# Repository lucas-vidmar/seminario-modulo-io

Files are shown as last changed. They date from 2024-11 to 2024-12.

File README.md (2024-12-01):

# Módulo Input / Output (I/O) para entornos educativos

> **Autores:**
> - [Lucas Vidmar](https://github.com/lucas-vidmar)
> - [Joaquín Bergmann](https://github.com/JoacoBerg)
> - [Lucas Boiero](https://github.com/boierito)
>
> **Institución:**
> - [Universidad Argentina de la Empresa (UADE)](https://www.uade.edu.ar/)

## Descripción

Este proyecto consiste en un módulo de entrada/salida (I/O) para entornos educativos, que permite a los estudiantes interactuar con sensores y actuadores a través de una interfaz gráfica de usuario (GUI) en un navegador web. El módulo I/O se comunica con el microcontrolador a través de una interfaz I2C, y proporciona una API RESTful para controlar los pines GPIO, los convertidores analógico-digital (ADC) y digital-analógico (DAC), y los codificadores rotatorios.

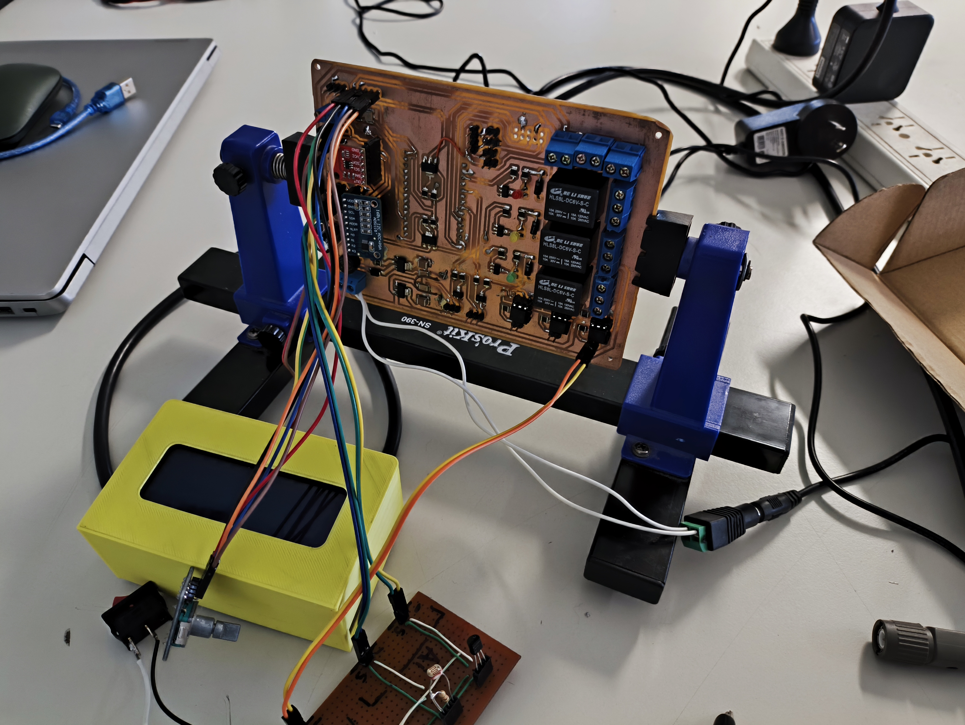
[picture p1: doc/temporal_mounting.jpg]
Montaje

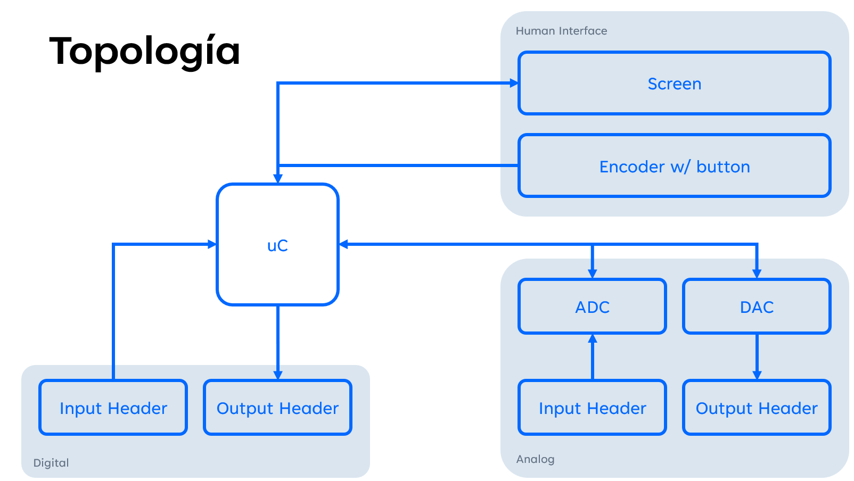
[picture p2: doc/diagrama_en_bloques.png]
Diagrama en bloques

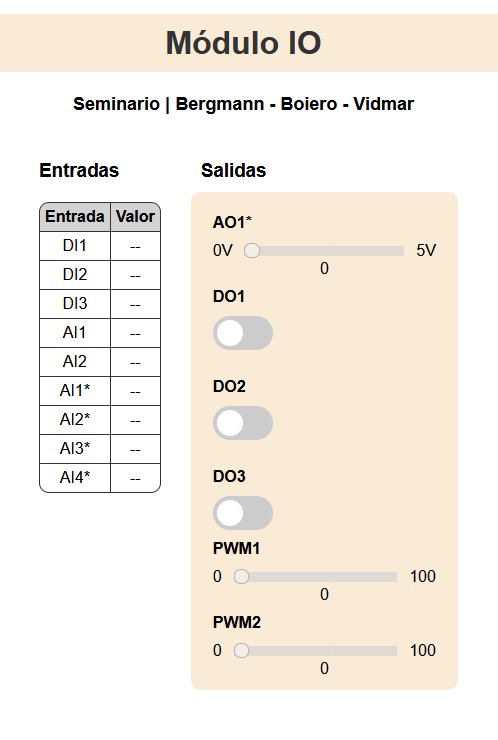
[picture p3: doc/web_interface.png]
Interfaz web


## Diseño de hardware

### Pinout

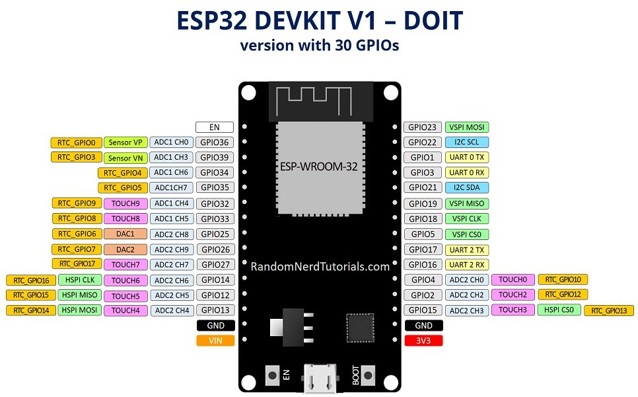
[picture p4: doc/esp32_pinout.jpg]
ESP32 Pinout

| Label | GPIO | Input/Output | Pines utilizados | Modo  |
|---|---|---|---|---|
| D2 | 2 | I/O | Pantalla | CS |
| D4 | 4 | I/O | PWM | PWM |
| D5 | 5 | I/O | PWM | PWM |
| D12 | 12 | I/O | Encoder | CLK |
| D13 | 13 | I/O | Encoder | DT |
| D14 | 14 | I/O | Encoder | SW |
| D15 | 15 | I/O | DO | DO |
| RX2 | 16 | I/O | U2_RXD | U2_RXD|
| TX2 | 17 | I/O | U2_TXD | U2_TXD|
| D18 | 18 | I/O | Pantalla | SCK |
| D19 | 19 | I/O | Pantalla | MISO  |
| D21 | 21 | I/O | I2C | SDA |
| D22 | 22 | I/O | I2C | SLC |
| D23 | 23 | I/O | Pantalla | MOSI  |
| D26 | 26 | I/O | DI | DI |
| D27 | 27 | I/O | DI | DI |
| D32 | 32 | I/O | DO | DO |
| D33 | 33 | I/O | DO | DO |
| D34 | 34 | I | ADC interno | ADC |
| D35 | 35 | I | ADC interno | ADC |
| VP | 36 | I | DI | DI |

### [Esquemático](kicad/Modulo%20IO%20Seminario.kicad_sch)

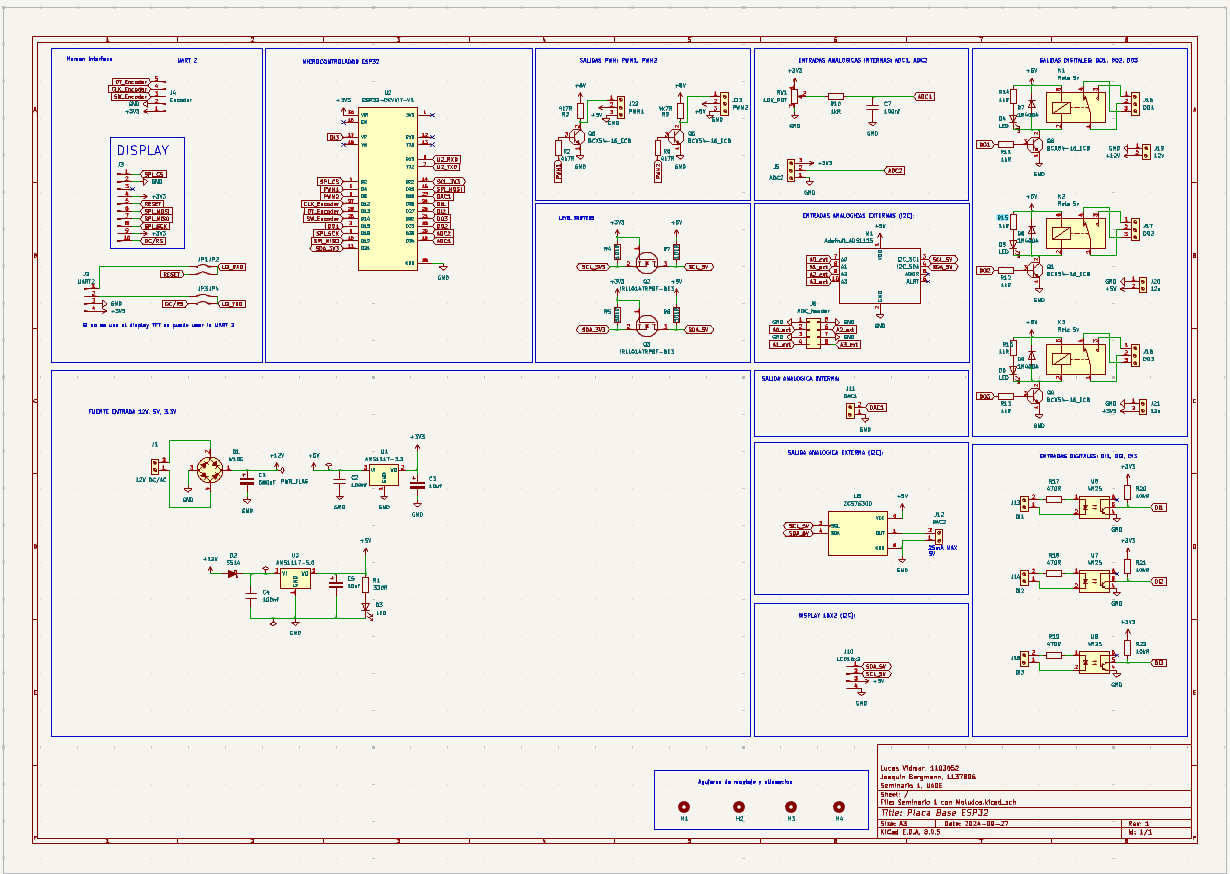
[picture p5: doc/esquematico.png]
Esquemático


### [PCB](kicad/Modulo%20IO%20Seminario.kicad_pcb)

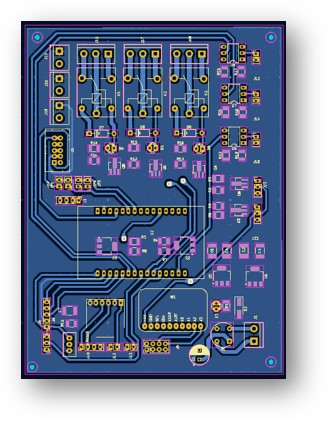
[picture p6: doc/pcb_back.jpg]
PCB Back

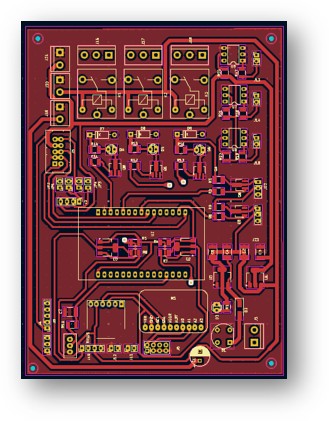
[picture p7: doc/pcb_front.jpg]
PCB Front

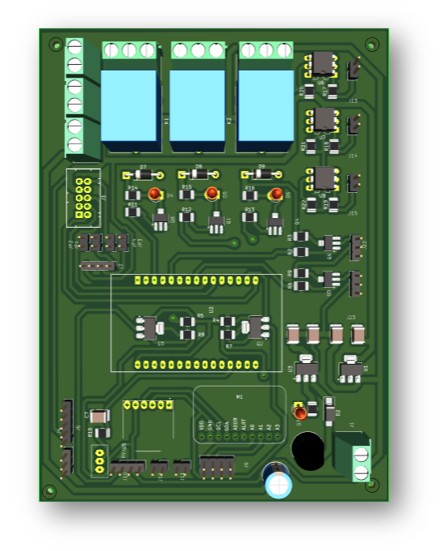
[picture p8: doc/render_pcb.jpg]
Render PCB


## Documentación de código

### [main.h](include/main.h)
Este archivo contiene las declaraciones principales del proyecto, incluidas las declaraciones de funciones para los manejadores de HTML, la impresión de menús, la lógica FSM y el control de GPIO.

### [led.h](include/led.h)
Este archivo contiene la declaración de la clase `BuiltInLed`, que proporciona métodos para controlar el LED incorporado en un microcontrolador.

### [lcdsim.h](include/lcdsim.h)
Este archivo contiene la declaración de la clase `SimulatedLCD`, que simula una pantalla LCD para fines de prueba.

### [i2c.h](include/i2c.h)
Este archivo contiene la declaración de la clase `I2C`, que proporciona métodos para inicializar la interfaz I2C y realizar operaciones de lectura y escritura en el bus I2C.

### [gpio.h](include/gpio.h)
Este archivo contiene la declaración de la clase `GPIO` y sus clases derivadas `DigitalGPIO` y `AnalogGPIO`, que proporcionan métodos para configurar, leer y escribir en los pines GPIO.

### [encodersim.h](include/encodersim.h)
Este archivo contiene la declaración de la clase `SimulatedEncoder`, que simula un codificador para fines de prueba.

### [encoder.h](include/encoder.h)
Este archivo contiene la declaración de la clase `Encoder`, que proporciona métodos para interactuar con un codificador rotatorio.

### [dac.h](include/dac.h)
Este archivo contiene la declaración de la clase `DAC`, que proporciona métodos para inicializar y controlar un Convertidor Digital a Analógico (DAC) a través de I2C.

### [adc.h](include/adc.h)
Este archivo contiene la declaración de la clase `ADC`, que proporciona métodos para interactuar con un Convertidor Analógico a Digital (ADC) a través de I2C.

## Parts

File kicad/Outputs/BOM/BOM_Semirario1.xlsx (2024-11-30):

Reference |  | Value | Footprint | Qty | Mfg Part # | Mouser | Reemplazo
C1 |  | 680uF | Capacitor_THT:CP_Radial_D8.0mm_P3.80mm | 1
C2;C4;C6;C7;C8;C9 | x | 100nf | Capacitor_SMD:C_1812_4532Metric_Pad1.57x3.40mm_HandSolder | 6 | -- valores mixtos -- | 18123C104JAT2A
C3;C5 | x | 10uf | Capacitor_SMD:C_1812_4532Metric_Pad1.57x3.40mm_HandSolder | 2 |  | 1812YC106MAT2A
D1 | x | W10G | Diode_THT:Diode_Bridge_Round_D9.8mm | 1
D2 | x | SS14 | Diode_SMD:D_SMA_Handsoldering | 1 |  | SS14 | 1N5819
D3;D4;D5;D6 | x | LED | LED_THT:LED_D3.0mm | 4
D7;D8;D9 | x | 1N4004 | Diode_THT:D_DO-41_SOD81_P10.16mm_Horizontal | 3
J1 |  | 12V DC/AC | TerminalBlock:TerminalBlock_bornier-2_P5.08mm | 1
J2 |  | UART2 | Connector_PinHeader_2.54mm:PinHeader_1x04_P2.54mm_Vertical | 1
J3 |  | Conn_01x10_Pin | easyeda:CONN-TH_10P-P2.54_B10B-XADSS-N-LF-SN | 1 | B10B-XADSS-N(LF)(SN)
J4 |  | Encoder | Connector_PinHeader_2.54mm:PinHeader_1x05_P2.54mm_Vertical | 1
J5 |  | PWM1 | Connector_PinHeader_2.54mm:PinHeader_1x02_P2.54mm_Vertical | 1
J6 |  | PWM2 | Connector_PinHeader_2.54mm:PinHeader_1x02_P2.54mm_Vertical | 1
J7 |  | ADC3 | Connector_PinHeader_2.54mm:PinHeader_1x02_P2.54mm_Vertical | 1
J8 |  | ADC4 | Connector_PinHeader_2.54mm:PinHeader_1x02_P2.54mm_Vertical | 1
J9 |  | ADC2 | Connector_PinHeader_2.54mm:PinHeader_1x02_P2.54mm_Vertical | 1
J10 |  | LCD16x2 | Connector_PinHeader_2.54mm:PinHeader_1x04_P2.54mm_Vertical | 1
J11 |  | DAC1 | Connector_PinHeader_2.54mm:PinHeader_1x02_P2.54mm_Vertical | 1
J12 |  | DAC2 | Connector_PinHeader_2.54mm:PinHeader_1x02_P2.54mm_Vertical | 1
J13 |  | DI1 | Connector_PinHeader_2.54mm:PinHeader_1x02_P2.54mm_Vertical | 1
J14 |  | DI2 | Connector_PinHeader_2.54mm:PinHeader_1x02_P2.54mm_Vertical | 1
J15 |  | DI3 | Connector_PinHeader_2.54mm:PinHeader_1x02_P2.54mm_Vertical | 1
J16 |  | DO1 | TerminalBlock:TerminalBlock_bornier-3_P5.08mm | 1
J17 |  | DO2 | TerminalBlock:TerminalBlock_bornier-3_P5.08mm | 1
J18 |  | DO3 | TerminalBlock:TerminalBlock_bornier-3_P5.08mm | 1
J19;J20;J21 |  | 12v | TerminalBlock:TerminalBlock_bornier-2_P5.08mm | 3
JP1;JP2;JP3;JP4 |  | Jumper_2_Bridged | Connector_PinHeader_2.54mm:PinHeader_1x02_P2.54mm_Vertical | 4
K1;K2;K3 | x | Rele 5v | Relay_THT:Relay_SPDT_SANYOU_SRD_Series_Form_C | 3
Q1;Q4;Q5;Q6;Q8 | x | BCX54-16_ECB | easyeda:SOT-89_Custom | 5 |  | BCX54-16,115
Q2;Q3 | x | IRLL014TRPBF-BE3 | easyeda:SOT-223_Custom | 2 |  | IRLL014TRPBF-BE3
R1 | x | 330R | Resistor_SMD:R_1210_3225Metric_Pad1.30x2.65mm_HandSolder | 1 |  | CRCW1210330RFKEAHP
R2;R3;R6;R9 | x | 4k7R | Resistor_SMD:R_1210_3225Metric_Pad1.30x2.65mm_HandSolder | 4 |  | CRCW12104K70JNEAIF
R4;R5;R7;R8;R20;R21;R22 | x | 10kR | Resistor_SMD:R_1210_3225Metric_Pad1.30x2.65mm_HandSolder | 7 | RT0805BRD0710KL | CRCW121010K0JNEAIF
R10;R11;R12;R13;R14;R15;R16 | x | 1kR | Resistor_SMD:R_1210_3225Metric_Pad1.30x2.65mm_HandSolder | 7 |  | CRCW12101K00JNEAIF
R17;R18;R19 | x | 470R | Resistor_SMD:R_1210_3225Metric_Pad1.30x2.65mm_HandSolder | 3 |  | CRCW1210470RFKEAHP
RV1 | x | 10K_POT | Potentiometer_THT:Potentiometer_Bourns_3296W_Vertical | 1
U1 | x | AMS1117-3.3 | Package_TO_SOT_SMD:SOT-223-3_TabPin2 | 1 |  | LM1117MPX-3.3/NOPB
U2 | x | ESP32-DEVKIT-V1 | esp32:ESP_Test | 1
U3 | x | AMS1117-5.0 | Package_TO_SOT_SMD:SOT-223-3_TabPin2 | 1 |  | LM1117MPX-5.0/NOPB
U4 | x | MCP4725A0T | easyeda:SOT-23-6_L2.9-W1.6-P0.95-LS2.8-BR | 1 | MCP4725A0T-E/CH | MCP4725A0T-E/CH
U5 | x | ADS1115IDGS | Package_SO:TSSOP-10_3x3mm_P0.5mm | 1 |  | ADS1115IDGST
U6;U7;U8 | x | 4N25 | Package_DIP:DIP-6_W7.62mm | 3 |  | 4N25

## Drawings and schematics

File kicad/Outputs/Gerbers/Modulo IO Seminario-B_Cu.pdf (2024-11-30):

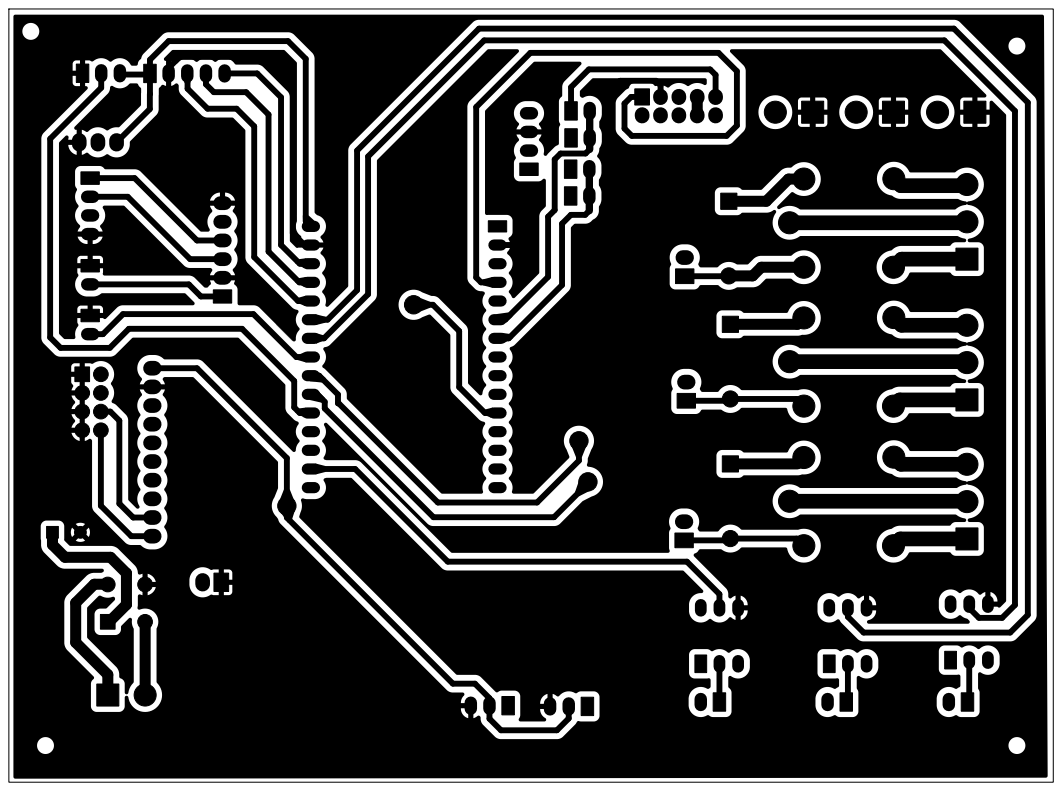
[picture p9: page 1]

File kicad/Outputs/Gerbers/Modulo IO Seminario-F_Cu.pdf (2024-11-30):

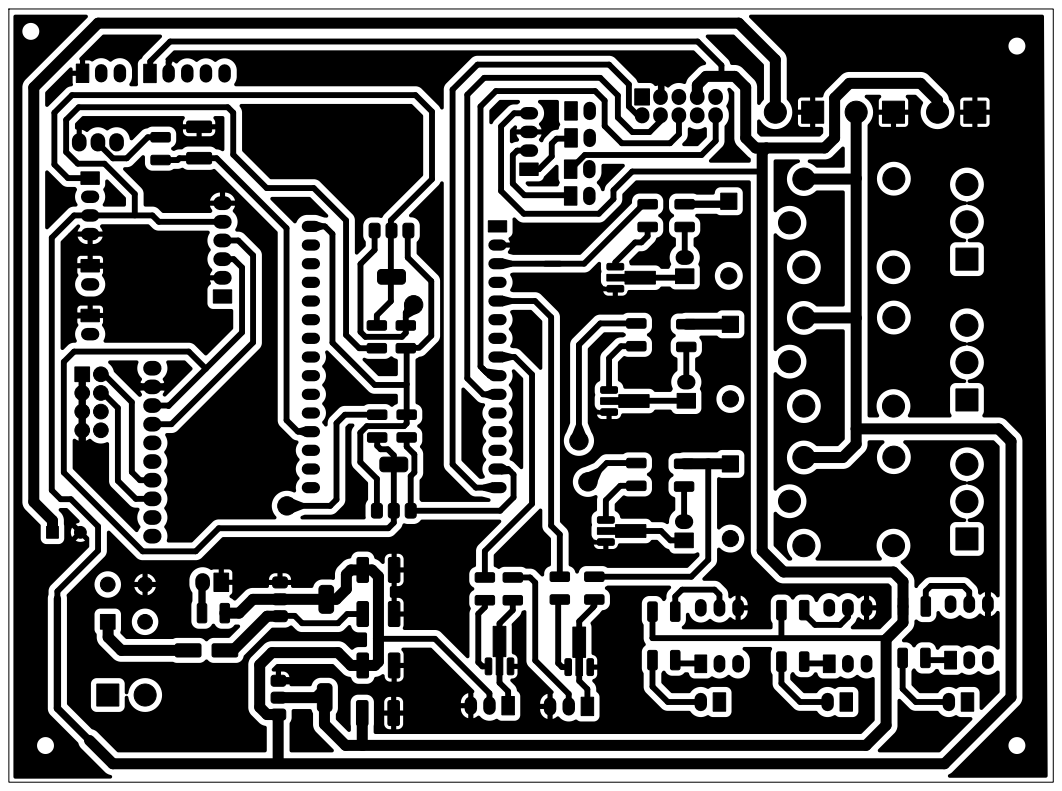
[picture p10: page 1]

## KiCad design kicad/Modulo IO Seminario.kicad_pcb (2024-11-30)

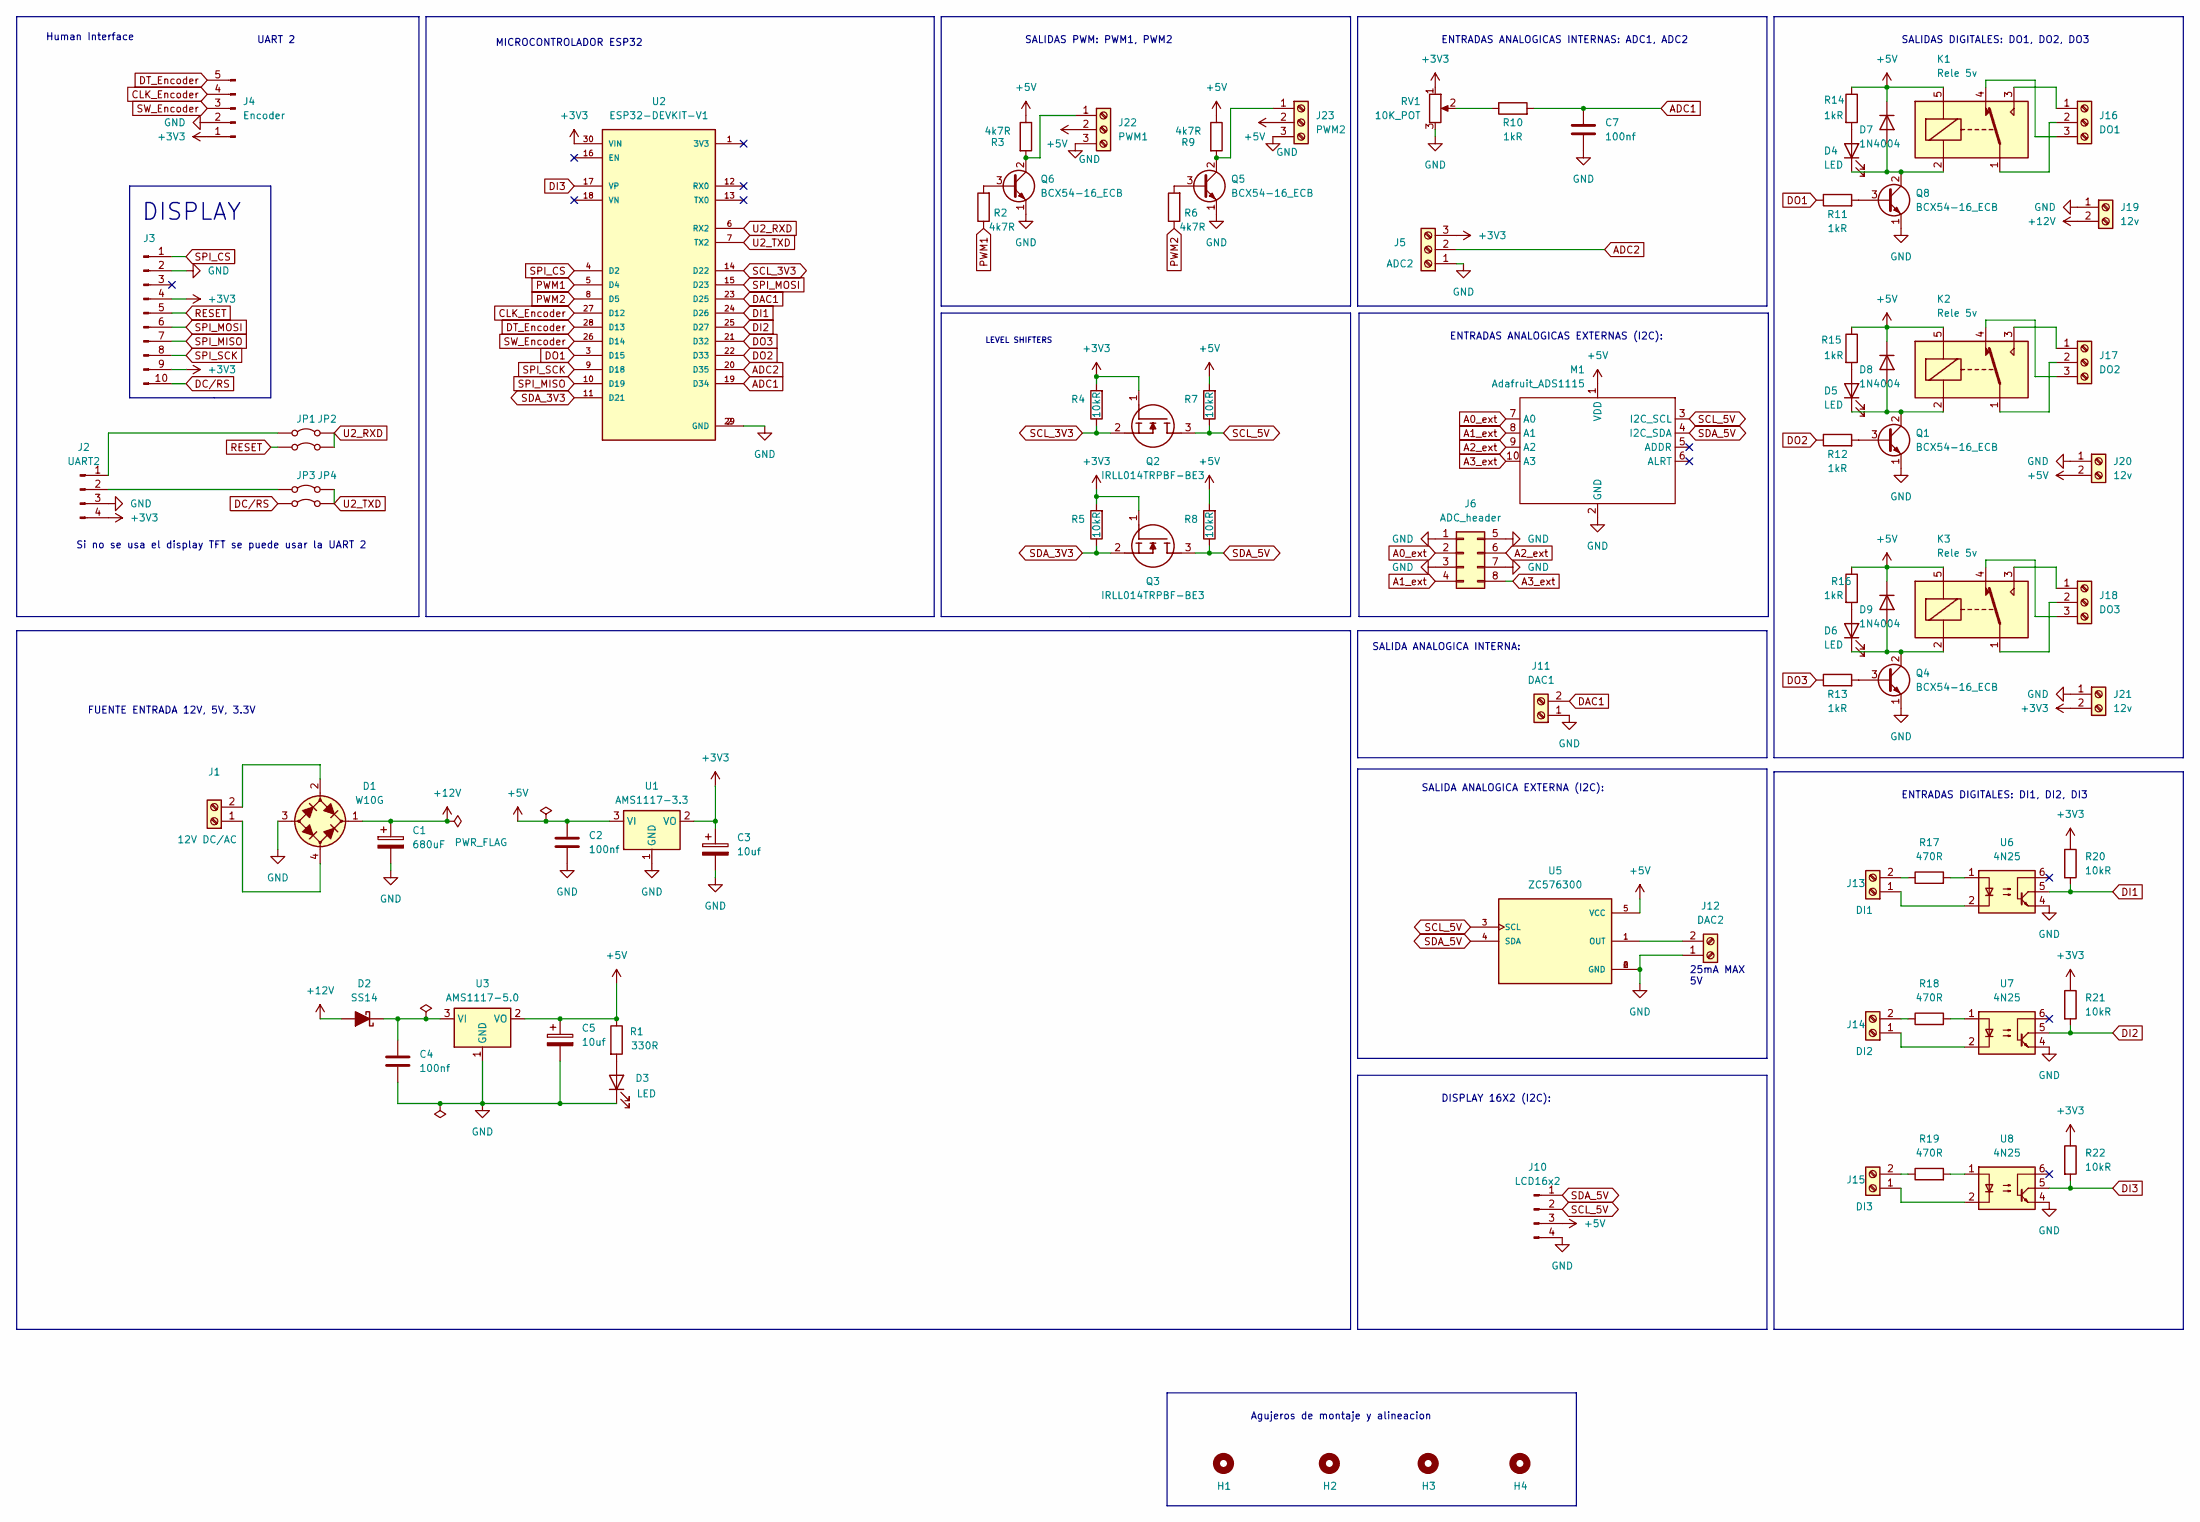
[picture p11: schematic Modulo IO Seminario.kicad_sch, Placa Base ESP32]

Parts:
C1: 680uF; CP_Radial_D8.0mm_P3.80mm
C2, C4, C7: 100nf; C_1812_4532Metric_Pad1.57x3.40mm_HandSolder; Mouser 18123C104JAT2A
C3, C5: 10uf; C_1812_4532Metric_Pad1.57x3.40mm_HandSolder; Mouser 1812YC106MAT2A
D1: W10G; Diode_Bridge_Round_D9.8mm
D2: SS14; D_SMA_Handsoldering; Mouser SS14
D3, D4, D5, D6: LED; led3mm
D7, D8, D9: 1N4004; D_DO-41_SOD81_P10.16mm_Horizontal
H1, H2, H3, H4: MountingHole_2.1mm
J1: 12V DC/AC; TerminalBlock_bornier-2_P5.08mm
J2: UART2; PinHeader_1.4_large
J3: Conn_01x10_Pin; CONN-TH_10P-P2.54_B10B-XADSS-N-LF-SN; Mfg Part # B10B-XADSS-N(LF)(SN); LCSC Part # C160278
J4: Encoder; PinHeader_1.5large
J5: ADC2; PinHeader_1.3_large
J6: ADC_header; PinHeader_2x04_custom
J10: LCD16x2; PinHeader_1.4_large
J11: DAC1; PinHeader_1.2_large
J12: DAC2; PinHeader_1.2_large
J13: DI1; PinHeader_1.2_large
J14: DI2; PinHeader_1.2_large
J15: DI3; PinHeader_1.2_large
J16: DO1; TerminalBlock_bornier-3_P5.08mm
J17: DO2; TerminalBlock_bornier-3_P5.08mm
J18: DO3; TerminalBlock_bornier-3_P5.08mm
J19, J20, J21: 12v; TerminalBlock_bornier-2_P5.08mm
J22: PWM1; PinHeader_1.3_large
J23: PWM2; PinHeader_1.3_large
JP1, JP2, JP3, JP4: Jumper_2_Bridged; PinHeader_1.2_large
K1, K2, K3: Rele 5v; Relay_SPDT_SANYOU_SRD_Series_Form_C
M1: Adafruit_ADS1115
Q1, Q4, Q5, Q6, Q8: BCX54-16_ECB; SOT-89_Custom; Mouser BCX54-16,115
Q2, Q3: IRLL014TRPBF-BE3; SOT-223_Custom; LCSC Part # C82045
R1: 330R; R_1210_3225Metric_Pad1.30x2.65mm_HandSolder; Mouser CRCW1210330RFKEAHP
R2, R3, R6, R9: 4k7R; R_1210_3225Metric_Pad1.30x2.65mm_HandSolder; Mouser CRCW12104K70JNEAIF
R4, R5, R7, R8: 10kR; R_1210_3225Metric_Pad1.30x2.65mm_HandSolder; Tolerancia 5%; Mfg Part # RT0805BRD0710KL; LCSC Part # C110775
R10, R11, R12, R13, R14, R15, R16: 1kR; R_1210_3225Metric_Pad1.30x2.65mm_HandSolder; Mouser CRCW12101K00JNEAIF
R17, R18, R19: 470R; R_1210_3225Metric_Pad1.30x2.65mm_HandSolder; Mouser CRCW1210470RFKEAHP
R20, R21, R22: 10kR; R_1210_3225Metric_Pad1.30x2.65mm_HandSolder; Mfg Part # RT0805BRD0710KL; Mouser CRCW121010K0JNEAIF
RV1: 10K_POT; PoteBourns
U1: AMS1117-3.3; SOT-223-3_TabPin2; Mouser LM1117MPX-3.3/NOPB
U2: ESP32-DEVKIT-V1; ESP_Test; PARTREV N/A
U3: AMS1117-5.0; SOT-223-3_TabPin2; Mouser LM1117MPX-5.0/NOPB
U5: ZC576300; MODULE_ZC576300; PARTREV v14
U6, U7, U8: 4N25; DIP-6_W7.62mm_LongPads; Mouser 4N25

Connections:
+3V3: C3.1, J2.4, J3.4, J3.9, J4.1, J5.3, J21.2, Q2.1 (G), Q3.1 (G), R4.2, R5.2, R20.1, R21.1, R22.1, RV1.1, U1.2 (VO), U2.30 (VIN)
+5V: C2.1, C5.1, D7.1 (K), D8.1 (K), D9.1 (K), J10.3, J20.2, J22.2, J23.2, K1.5, K2.5, K3.5, M1.1 (VDD), R1.1, R3.1, R7.2, R8.2, R9.1, R14.1, R15.1, R16.1, U1.3 (VI), U3.2 (VO), U5.5 (VCC)
+12V: C1.1, D1.1 (+), D2.2 (A), J19.2
A0_ext: J6.2, M1.7 (A0)
A1_ext: J6.4, M1.8 (A1)
A2_ext: J6.6, M1.9 (A2)
A3_ext: J6.8, M1.10 (A3)
ADC1: C7.1, R10.2, U2.19 (D34)
ADC2: J5.2, U2.20 (D35)
CLK_Encoder: J4.4, U2.27 (D12)
DAC1: J11.2, U2.23 (D25)
DC/RS: J3.10, JP4.1 (A)
DI1: R20.2, U2.24 (D26), U6.5
DI2: R21.2, U2.25 (D27), U7.5
DI3: R22.2, U2.17 (VP), U8.5
DO1: R11.1, U2.3 (D15)
DO2: R12.1, U2.22 (D33)
DO3: R13.1, U2.21 (D32)
DT_Encoder: J4.5, U2.28 (D13)
GND: C1.2, C2.2, C3.2, C4.2, C5.2, C7.2, D1.3 (-), D3.1 (K), J2.3, J3.2, J4.2, J5.1, J6.1, J6.3, J6.5, J6.7, J10.4, J11.1, J12.1, J19.1, J20.1, J21.1, J22.3, J23.3, M1.2 (GND), Q1.1 (E), Q4.1 (E), Q5.1 (E), Q6.1 (E), Q8.1 (E), RV1.3, U1.1 (GND), U2.2 (GND), U2.29 (GND), U3.1 (GND), U5.2 (GND), U5.6 (GND), U6.4, U7.4, U8.4
unnamed: D1.2 (1), J1.2
unnamed: D1.4 (2), J1.1
unnamed: C4.1, D2.1 (K), U3.3 (VI)
unnamed: D3.2 (A), R1.2
unnamed: D4.2 (A), R14.2
unnamed: D4.1 (K), D7.2 (A), K1.2, Q8.2 (C)
unnamed: D5.2 (A), R15.2
unnamed: D5.1 (K), D8.2 (A), K2.2, Q1.2 (C)
unnamed: D6.2 (A), R16.2
unnamed: D6.1 (K), D9.2 (A), K3.2, Q4.2 (C)
unnamed: J2.1, JP1.1 (A)
unnamed: J2.2, JP3.1 (A)
unnamed: J12.2, U5.1 (OUT)
unnamed: J13.1, U6.2
unnamed: J13.2, R17.1
unnamed: J14.1, U7.2
unnamed: J14.2, R18.1
unnamed: J15.1, U8.2
unnamed: J15.2, R19.1
unnamed: J16.1, K1.3
unnamed: J16.2, K1.1
unnamed: J16.3, K1.4
unnamed: J17.1, K2.3
unnamed: J17.2, K2.1
unnamed: J17.3, K2.4
unnamed: J18.1, K3.3
unnamed: J18.2, K3.1
unnamed: J18.3, K3.4
unnamed: J22.1, Q6.2 (C), R3.2
unnamed: J23.1, Q5.2 (C), R9.2
unnamed: Q1.3 (B), R12.2
unnamed: Q4.3 (B), R13.2
unnamed: Q5.3 (B), R6.2
unnamed: Q6.3 (B), R2.2
unnamed: Q8.3 (B), R11.2
unnamed: R10.1, RV1.2
unnamed: R17.2, U6.1
unnamed: R18.2, U7.1
unnamed: R19.2, U8.1
PWM1: R2.1, U2.5 (D4)
PWM2: R6.1, U2.8 (D5)
RESET: J3.5, JP2.1 (A)
SCL_3V3: Q2.2 (S), R4.1, U2.14 (D22)
SCL_5V: J10.2, M1.3 (I2C_SCL), Q2.3 (D), R7.1, U5.3 (SCL)
SDA_3V3: Q3.2 (S), R5.1, U2.11 (D21)
SDA_5V: J10.1, M1.4 (I2C_SDA), Q3.3 (D), R8.1, U5.4 (SDA)
SPI_CS: J3.1, U2.4 (D2)
SPI_MISO: J3.7, U2.10 (D19)
SPI_MOSI: J3.6, U2.15 (D23)
SPI_SCK: J3.8, U2.9 (D18)
SW_Encoder: J4.3, U2.26 (D14)
U2_RXD: JP1.2 (B), JP2.2 (B), U2.6 (RX2)
U2_TXD: JP3.2 (B), JP4.2 (B), U2.7 (TX2)

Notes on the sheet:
SALIDA ANALOGICA INTERNA:
UART 2
Si no se usa el display TFT se puede usar la UART 2
Agujeros de montaje y alineacion
25mA MAX 5V
MICROCONTROLADOR ESP32
ENTRADAS DIGITALES: DI1, DI2, DI3
DISPLAY 16X2 (I2C):
SALIDA ANALOGICA EXTERNA (I2C):
ENTRADAS ANALOGICAS INTERNAS: ADC1, ADC2
FUENTE ENTRADA 12V, 5V, 3.3V
ENTRADAS ANALOGICAS EXTERNAS (I2C):
Human Interface
SALIDAS DIGITALES: DO1, DO2, DO3
LEVEL SHIFTERS
DISPLAY
SALIDAS PWM: PWM1, PWM2

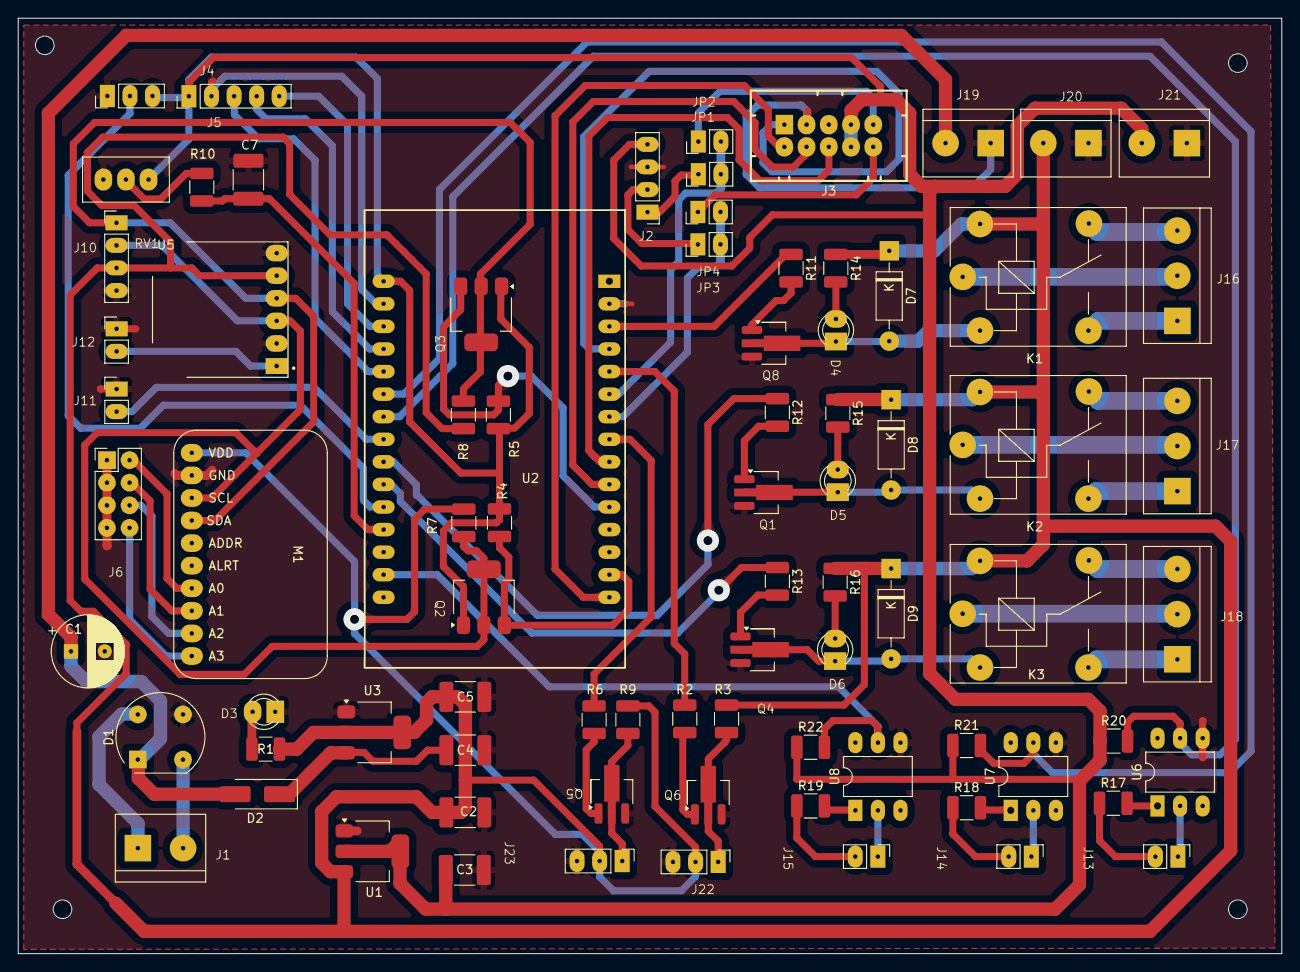
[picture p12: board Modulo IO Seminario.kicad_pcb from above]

Board: 2 copper layers, 142.2 x 105.2 mm, 84 parts (0 on the bottom side), 73 nets.

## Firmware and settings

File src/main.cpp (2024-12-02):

#include "main.h"

bool print = true;
bool wifiConfig = true;

/* ------- Perifericos ------- */
BuiltInLed led = BuiltInLed();
I2C i2c = I2C();
DAC dac = DAC();
ADC adc = ADC();
#ifdef USE_LCD
LiquidCrystal_I2C lcd(0x27, 20, 4);  // Crear el objeto lcd con dirección 0x3F y 20 columnas x 4 filas
#else
SimulatedLCD lcd = SimulatedLCD();
#endif
#ifdef USE_ENCODER
Encoder encoder = Encoder();
#else
SimulatedEncoder encoder = SimulatedEncoder();
#endif

/* ------- Web Server ------- */
const String ssid = "Modulo IO";
const String password = "iomodule";
WebServerESP32 webServer(ssid.c_str(), password.c_str());

/* ------- GPIOs ------- */
// DI: 26 27 36 | DO: 15 32 33
DigitalGPIO di1 = DigitalGPIO(DI1, INPUT);
DigitalGPIO di2 = DigitalGPIO(DI2, INPUT);
DigitalGPIO di3 = DigitalGPIO(DI3, INPUT);
DigitalGPIO do1 = DigitalGPIO(DO1, OUTPUT);
DigitalGPIO do2 = DigitalGPIO(DO2, OUTPUT);
DigitalGPIO do3 = DigitalGPIO(DO3, OUTPUT);
// AI: 34 35 | AO: 25
AnalogGPIO ai1 = AnalogGPIO(AI1);
AnalogGPIO ai2 = AnalogGPIO(AI2);
//AnalogGPIO ao1 = AnalogGPIO(AO1);
PWM pwm1 = PWM(PPWM1, PWMFREQ, 0);
PWM pwm2 = PWM(PPWM2, PWMFREQ, 0);

I2CScanner scanner;

/* ------- Menu ------- */
enum MenuState {
  MAIN_MENU,
  MEASUREMENTS,
  CONTROL_MENU,
  CONTROL,
  CONFIG
};

enum ControlState {
  CONTROL_DO1,
  CONTROL_DO2,
  CONTROL_DO3,
  CONTROL_AO1,
  CONTROL_PWM1,
  CONTROL_PWM2,
  CONTROL_EXIT
};

void setup() {

  Serial.begin(115200);

  // I2C Scanner
  scanner.Init();
  scanner.Scan();

  // Inicializaciones
  led.init();
  led.blink(500);

  // Inicializar SPIFFS
  Serial.println("Inicializando SPIFFS...");
  if (!SPIFFS.begin(true)) {
    Serial.println("Error al montar SPIFFS");
    return;
  }
  
  // Inicializacion de perifericos
  Serial.println("Inicializando periféricos...");
  i2c.init();
  dac.init(&i2c);
  adc.init(&i2c);
  encoder.init();

  // Setup pines
  Serial.println("Configurando pines...");
  di1.setup();
  di2.setup();
  di3.setup();
  do1.setup();
  do2.setup();
  do3.setup();
  ai1.setup();
  ai2.setup();
  //ao1.setup();

  // Configurar manejadores para rutas
  Serial.println("Configurando manejadores de rutas...");
  HTMLHandlers();

  // Settear PWM a 0
  pwm1.setDutyCycle(0);
  pwm2.setDutyCycle(0);
  
  // Iniciar el servidor web
  Serial.println("Iniciando servidor web...");
  webServer.setDefaultFile("index.html");
  webServer.begin();

  // Mostrar información en la pantalla
  lcd.init();
  lcd.backlight();
  lcd.clear();
  String ops[] = {"IP: " + WiFi.softAPIP().toString(), "SSID: " + ssid, "Password: " + password, "Continuar"};
  while (!(encoder.isButtonPressed() && encoder.getPosition() == 3)) { // Esperar a que el usuario presione el botón y seleccione "Continuar"
    if (encoder.moved() || printOneTime()) {
      print_menu(ops, 4, "Informacion AP");
    }
    encoder.update();
  }
  encoder.setPosition(0);
}

void loop(){
  encoder.update();
  fsm();
}

void HTMLHandlers() {
  webServer.on("/", HTTP_GET, [](AsyncWebServerRequest *request){
      request->send(SPIFFS, "/index.html", "text/html");
  });

  // Leer entradas digitales
  webServer.on("/readDI1", HTTP_GET, [](AsyncWebServerRequest *request){
    int state = digitalRead(DI1);
    request->send(200, "text/plain", String(state));
  });

  webServer.on("/readDI2", HTTP_GET, [](AsyncWebServerRequest *request){
    int state = digitalRead(DI2);
    request->send(200, "text/plain", String(state));
  });

  webServer.on("/readDI3", HTTP_GET, [](AsyncWebServerRequest *request){
    int state = digitalRead(DI3);
    request->send(200, "text/plain", String(state));
  });
  // Leer entradas analógicas
  webServer.on("/readAI1", HTTP_GET, [](AsyncWebServerRequest *request){
    float value = analogRead(AI1)*3.3/4095;
    request->send(200, "text/plain", String(value,2));
  });

  webServer.on("/readAI2", HTTP_GET, [](AsyncWebServerRequest *request){
    float value = analogRead(AI2)*3.3/4095;
    request->send(200, "text/plain", String(value,2));
  });

  webServer.on("/readAI1*", HTTP_GET, [](AsyncWebServerRequest *request){
    float value = adc.read_voltage(0);
    request->send(200, "text/plain", String(value,2));
  });

  webServer.on("/readAI2*", HTTP_GET, [](AsyncWebServerRequest *request){
    float value = adc.read_voltage(1);
    request->send(200, "text/plain", String(value,2));
  });

  webServer.on("/readAI3*", HTTP_GET, [](AsyncWebServerRequest *request){
    float value = adc.read_voltage(2);
    request->send(200, "text/plain", String(value,2));
  });

  webServer.on("/readAI4*", HTTP_GET, [](AsyncWebServerRequest *request){
    float value = adc.read_voltage(3);
    request->send(200, "text/plain", String(value,2));
  });

  // Ajustar salida analógica
  webServer.on("/setAO1*", HTTP_GET, [](AsyncWebServerRequest *request){
    if (request->hasParam("value")) {
      String valueStr = request->getParam("value")->value();
      int value = valueStr.toInt();
      dac.digitalWrite(value);
      request->send(200, "text/plain", "AO1* ajustado a " + valueStr);
    } else {
      request->send(400, "text/plain", "Falta el parámetro 'value'");
    }
  });

  // Ajustar PWM1
  webServer.on("/setPWM1", HTTP_GET, [](AsyncWebServerRequest *request){
    if (request->hasParam("duty")) {
      String dutyStr = request->getParam("duty")->value();
      int duty = dutyStr.toInt();
      pwm1.setDutyCycle(100-duty);
      request->send(200, "text/plain", "PWM1 ajustado a " + dutyStr);
    } else {
      request->send(400, "text/plain", "Faltan parámetro 'duty'");
    }
  });
  // Ajustar PWM2
  webServer.on("/setPWM2", HTTP_GET, [](AsyncWebServerRequest *request){
    if (request->hasParam("duty")) {
      String dutyStr = request->getParam("duty")->value();
      int duty = dutyStr.toInt();
      pwm2.setDutyCycle(100-duty);
      request->send(200, "text/plain", "PWM2 ajustado a " + dutyStr);
    } else {
      request->send(400, "text/plain", "Faltan parámetro 'duty'");
    }
  });

  // Ajustar salidas digitales
  webServer.on("/setDO1", HTTP_GET, [](AsyncWebServerRequest *request){
    if (request->hasParam("state")) {
      String stateStr = request->getParam("state")->value();
      int state = stateStr.toInt();
      digitalWrite(DO1, state);
      request->send(200, "text/plain", "DO1 ajustado a " + stateStr);
    } else {
      request->send(400, "text/plain", "Falta el parámetro 'state'");
    }
  });

  webServer.on("/setDO2", HTTP_GET, [](AsyncWebServerRequest *request){
    if (request->hasParam("state")) {
      String stateStr = request->getParam("state")->value();
      int state = stateStr.toInt();
      digitalWrite(DO2, state);
      request->send(200, "text/plain", "DO2 ajustado a " + stateStr);
    } else {
      request->send(400, "text/plain", "Falta el parámetro 'state'");
    }
  });

  webServer.on("/setDO3", HTTP_GET, [](AsyncWebServerRequest *request){
    if (request->hasParam("state")) {
      String stateStr = request->getParam("state")->value();
      int state = stateStr.toInt();
      digitalWrite(DO3, state);
      request->send(200, "text/plain", "DO3 ajustado a " + stateStr);
    } else {
      request->send(400, "text/plain", "Falta el parámetro 'state'");
    }
  });

}

void fsm() {
  static MenuState state = MAIN_MENU;
  static ControlState control_state = CONTROL_DO1;
  switch (state) {
    case MAIN_MENU:
      // Manejar el menú principal
      if (encoder.moved() || printOneTime()) {
        String menuOptions[] = {"Mediciones", "Control", "Configuracion"};
        print_menu(menuOptions, 3, "Menu principal");
      }
      if (encoder.isButtonPressed()) {
        switch (encoder.getPosition()){
          case 0:
            state = MEASUREMENTS;
            break;
          case 1:
            state = CONTROL_MENU;
            break;
          case 2:
            state = CONFIG;
            break;
        }
        encoder.setPosition(0);
        print = true;
      }
      break;
    case MEASUREMENTS:
      // Manejar las mediciones
      static int time = millis();
      if (encoder.moved() || millis() - time > 1000 || printOneTime()) { // Imprimir medidas si el encoder se mueve o ha pasado 1s
        time = millis();
        print_measurments();
      }
      if (encoder.isButtonPressed() && encoder.getPosition() == 9) {
        state = MAIN_MENU;
        encoder.setPosition(0);
        print = true;
      }
      break;
    case CONTROL_MENU:
      // Manejar el menu de control
      if (encoder.moved() || printOneTime()) print_control(encoder.getPosition());
      if (encoder.isButtonPressed()) {
        state = (encoder.getPosition() == CONTROL_EXIT) ? MAIN_MENU : CONTROL; // Salir del menu de control o ir a control
        control_state = ControlState(encoder.getPosition());
        encoder.setPosition(0);
        print = true;
      }
      break;
    case CONTROL:
      // Manejar el control
      switch (control_state) {
        case CONTROL_DO1:
          if (encoder.moved() || printOneTime()) control_digital(do1, "DO1");
          if (encoder.isButtonPressed()) {
            if (encoder.getPosition() == 0) {
              do1.toggle();
              control_digital(do1, "DO1");
            }
            else {
              state = CONTROL_MENU;
              encoder.setPosition(0);
              print = true;
            }
          }
          break;
        case CONTROL_DO2:
          if (encoder.moved() || printOneTime()) control_digital(do2, "DO2");
          if (encoder.isButtonPressed()) {
            if (encoder.getPosition() == 0) {
              do2.toggle();
              control_digital(do2, "DO2");
            }
            else {
              state = CONTROL_MENU;
              encoder.setPosition(0);
              print = true;
            }
          }
          break;
        case CONTROL_DO3:
          if (encoder.moved() || printOneTime()) control_digital(do3, "DO3");
          if (encoder.isButtonPressed()) {
            if (encoder.getPosition() == 0) {
              do3.toggle();
              control_digital(do3, "DO3");
            }
            else {
              state = CONTROL_MENU;
              encoder.setPosition(0);
              print = true;
            }
          }
          break;
        case CONTROL_AO1:
          encoder.setMaxPosition(5000/100);
          encoder.setMinPosition(0);
          while (!encoder.isButtonPressed()) {
            if (encoder.moved() || printOneTime()) {
              int val = encoder.getPosition() * 100;
              int digitalVal = (int)(val * DAC_MAX_DIGITAL_VALUE / 5000);
              dac.digitalWrite(digitalVal);
              control_dac(dac, "AO1");
            }
            encoder.update();
          }
          state = CONTROL_MENU;
          encoder.setPosition(0);
          print = true;
          break;
        case CONTROL_PWM1:
          encoder.setMaxPosition(10);
          encoder.setMinPosition(0);
          while (!encoder.isButtonPressed()) {
            if (encoder.moved() || printOneTime()) {
              pwm1.setDutyCycle(100 - encoder.getPosition() * 10); // Ajustar el ciclo de trabajo de 10 en 10
              control_pwm(pwm1, "PWM1");
            }
            encoder.update();
          }
          state = CONTROL_MENU;
          encoder.setPosition(0);
          print = true;
          break;
        case CONTROL_PWM2:
          encoder.setMaxPosition(10);
          encoder.setMinPosition(0);
          while (!encoder.isButtonPressed()) {
            if (encoder.moved() || printOneTime()) {
              pwm2.setDutyCycle(100 - encoder.getPosition() * 10); // Ajustar el ciclo de trabajo de 10 en 10
              control_pwm(pwm2, "PWM2");
            }
            encoder.update();
          }
          state = CONTROL_MENU;
          encoder.setPosition(0);
          print = true;
          break;
        case CONTROL_EXIT:
          state = CONTROL_MENU;
          encoder.setPosition(0);
          print = true;
          break;
      }
      break;
    case CONFIG:
      // Manejar la configuración de WiFi
      static String opsWiFi[] = {"IP: " + WiFi.softAPIP().toString(), "SSID: " + ssid, "Password: " + password, "Continuar"};
      if (encoder.moved() || printOneTime()) {
        print_menu(opsWiFi, 4, "Config AP");
      }
      if (encoder.isButtonPressed() && encoder.getPosition() == 3) {
        state = MAIN_MENU;
        encoder.setPosition(0);
        print = true;
      }
      break;
  }
}

void print_menu(String options[],int options_size, String title) {
  lcd.clear();
  encoder.setMinPosition(0);
  encoder.setMaxPosition(options_size - 1);
  int selected = encoder.getPosition();
  print_line(0, "--" + title + "--");
  int options_to_print = min(LCD_ROWS - 1, options_size);

  String menuItems[options_to_print];
  int group = selected / (LCD_ROWS - 1);
  int start = group * (LCD_ROWS - 1);
  for (int i = 0; i < options_to_print; i++) {
    if (start + i >= options_size) {
      break;
    }
    if (start + i == selected) {
      menuItems[i] = ">" + options[start + i]; // Agregar un indicador de selección
    } else {
      menuItems[i] = options[start + i];
    }
  }
  for (int i = 0; i < options_to_print; i++) {
    print_line(i+1, menuItems[i]); // Imprimir cada elemento del menú
  } 
  
}

void print_line(int line, String text) {
  lcd.setCursor(0, line);
  lcd.print(text.c_str());
  #ifdef USE_LCD
  Serial.println(text);
  #endif
}

void print_measurments() {
  lcd.clear();
  String options[]= {
    "DI1: " + String(digitalRead(DI1) ? "OFF" : "ON"),
    "DI2: " + String(digitalRead(DI2) ? "OFF" : "ON"),
    "DI3: " + String(digitalRead(DI3) ? "OFF" : "ON"),
    "AI1: " + String(analogRead(AI1)),
    "AI2: " + String(analogRead(AI2)),
    "AI1*: " + String(adc.read_voltage(0)),
    "AI2*: " + String(adc.read_voltage(1)),
    "AI3*: " + String(adc.read_voltage(2)),
    "AI4*: " + String(adc.read_voltage(3)),
    "Volver"
  };
  print_menu(options, 10, "Mediciones");
}

void print_control(int selected){
  String controlItems[] = {"DO1", "DO2", "DO3", "AO1", "PWM1", "PWM2", "Volver"};
  print_menu(controlItems, 7, "Control");
}

void control_digital(DigitalGPIO d, String pinName){
  String status = d.read() == HIGH ? "OFF" : "ON";
  String options[] = {status, "Volver"};
  print_menu(options, 2, pinName);
}

void control_dac(DAC d, String pinName){
  lcd.clear();
  print_line(0, "--Control de " + pinName + "--");
  float vinV = d.readVoltage() / 1000.0;
  print_line(1, "Valor: " + String(vinV, 2) + "V");
}

void control_pwm(PWM p, String pinName){
  lcd.clear();
  print_line(0, "--Control de " + pinName + "--");
  print_line(1, "Duty: " + String(p.getDutyCycle()*100/255) + "%");
}

bool printOneTime() { // Función para imprimir solo una vez
  if (print) {
    print = false;
    return true;
  }
  return false;
}

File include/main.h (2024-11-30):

/**
 * @file main.h
 * @brief Archivo de encabezado principal para el proyecto.
 *
 * Este archivo contiene las declaraciones de funciones y variables utilizadas en el proyecto.
 * Incluye la inicialización de módulos, la configuración de HTML, la lógica de la máquina de estados finitos (FSM),
 * y la impresión de mediciones y menús.
 */
#pragma once

#include <Arduino.h>
#include "I2CScanner.h"

/*-- Módulos --*/
#include "encoder.h"
#include "led.h"
#include "i2c.h"
#include "dac.h"
#include "adc.h"
#include "gpio.h"
#include "webserver.h"
#include "LiquidCrystal_I2C.h"
#include "lcdsim.h"
#include "encodersim.h"
#include "pwm.h"

// Definir GPIOs
#define DI1 GPIO_NUM_26
#define DI2 GPIO_NUM_27
#define DI3 GPIO_NUM_36
#define DO1 GPIO_NUM_15
#define DO2 GPIO_NUM_33
#define DO3 GPIO_NUM_32
#define AI1 GPIO_NUM_34
#define AI2 GPIO_NUM_35
//#define AO1 GPIO_NUM_25
#define PPWM1 GPIO_NUM_4
#define PPWM2 GPIO_NUM_5
#define PWMFREQ 50

#define USE_LCD
#define USE_ENCODER

/**
 * @brief Inicializa y configura los manejadores de HTML.
 *
 * Esta función es responsable de configurar los manejadores necesarios
 * para procesar contenido HTML. Debe ser llamada durante la fase de 
 * inicialización de la aplicación para asegurar que todas las funcionalidades 
 * relacionadas con HTML estén correctamente configuradas.
 */
void HTMLHandlers();

/**
 * @brief Imprime un menú con las opciones y el título dados.
 * 
 * @param options Un array de cadenas que representan las opciones del menú.
 * @param options_size El número de opciones en el menú.
 * @param title El título del menú.
 */
void print_menu(String options[], int options_size, String title);

/**
 * @brief Imprime una línea de texto.
 * 
 * Esta función imprime el texto especificado en el número de línea dado.
 * 
 * @param line El número de línea donde se debe imprimir el texto.
 * @param text El texto a imprimir.
 */
void print_line(int line, String text);

/**
 * @brief Función para manejar la lógica de la máquina de estados finitos (FSM).
 *
 * Esta función es responsable de gestionar los estados y transiciones
 * de la máquina de estados finitos. Debe ser llamada periódicamente para
 * asegurar que la FSM opere correctamente.
 */
void fsm();

/**
 * @brief Imprime las mediciones en la salida estándar.
 *
 * Esta función recupera e imprime las mediciones de manera formateada.
 * Los detalles específicos de las mediciones y su formato dependen de la 
 * implementación.
 */
void print_measurments();

/**
 * @brief Imprime un mensaje una sola vez.
 * 
 * Esta función está destinada a imprimir un mensaje específico o realizar una acción específica solo una vez.
 * 
 * @return true si el mensaje se imprimió correctamente, false en caso contrario.
 */
bool printOneTime();

/**
 * @brief Imprime la información de control basada en la opción seleccionada.
 * 
 * @param selected Un entero que representa la opción de control seleccionada.
 */
void print_control(int selected);

/**
 * @brief Controla un pin GPIO digital.
 * 
 * Esta función permite controlar un pin GPIO digital especificando el pin
 * y su nombre.
 * 
 * @param d El objeto DigitalGPIO que representa el pin digital a controlar.
 * @param pinName El nombre del pin como una cadena.
 */
void control_digital(DigitalGPIO d, String pinName);

/**
 * @brief Controla un pin GPIO analógico.
 * 
 * @param a Una instancia de AnalogGPIO que representa el GPIO analógico a controlar.
 * @param pinName Una cadena que representa el nombre del pin a controlar.
 */
void control_analog(AnalogGPIO a, String pinName);

/**
 * @brief Controla el DAC (Convertidor Digital a Analógico) basado en el pin especificado.
 * 
 * @param d El objeto DAC a controlar.
 * @param pinName El nombre del pin asociado con el DAC.
 */
void control_dac(DAC d, String pinName);

/**
 * @brief Controla la señal PWM en un pin especificado.
 * 
 * @param p El objeto PWM que contiene la configuración para la señal PWM.
 * @param pinName El nombre del pin donde se aplicará la señal PWM.
 */
void control_pwm(PWM p, String pinName);

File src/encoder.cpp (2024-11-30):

#include "encoder.h"

// Inicializar puntero de instancia estática
Encoder* Encoder::instance = nullptr;

// Constructor para inicializar el estado del encoder
Encoder::Encoder() : lastState(LOW), position(0), buttonPressed(false), encoderMaxPosition(10), encoderMinPosition(1) { }

// Inicializar pines y interrupciones del encoder
void Encoder::init() {
    pinMode(ENCODER_CLK, INPUT);
    pinMode(ENCODER_DT, INPUT);
    pinMode(ENCODER_SW, INPUT_PULLUP);
    lastState = digitalRead(ENCODER_CLK);

    instance = this;

    // Adjuntar interrupciones sin llamar a gpio_install_isr_service
    attachInterrupt(digitalPinToInterrupt(ENCODER_CLK), handleInterrupt, CHANGE);
    attachInterrupt(digitalPinToInterrupt(ENCODER_SW), handleButtonInterrupt, FALLING);
}

// Manejador de interrupciones para la rotación del encoder
void IRAM_ATTR Encoder::handleInterrupt() {
    static unsigned long lastInterruptTime = 0;
    unsigned long interruptTime = millis();
    
    // Antirrebote: ignorar interrupciones que ocurren dentro de los 15ms de la última interrupción
    if (interruptTime - lastInterruptTime > ENCODER_ROTATION_DEBOUNCE) {
        if (instance) {
            int state = digitalRead(ENCODER_CLK);
            if (state != instance->lastState) { // Si el estado ha cambiado, ocurrió un pulso
                if (digitalRead(ENCODER_DT) != state) { // Si el estado de DT es diferente del estado de CLK
                    instance->position++;
                } else {
                    instance->position--;
                }
                instance->lastState = state;
            }
        }
    }
    lastInterruptTime = interruptTime;
}

// Manejador de interrupciones para la pulsación del botón
void IRAM_ATTR Encoder::handleButtonInterrupt() {
    static unsigned long lastButtonInterruptTime = 0;
    unsigned long interruptTime = millis();
    
    // Antirrebote: ignorar interrupciones que ocurren dentro de los 50ms de la última interrupción
    if (interruptTime - lastButtonInterruptTime > ENCODER_BUTTON_DEBOUNCE) {
        if (instance) {
            instance->buttonPressed = true;
        }
    }
    lastButtonInterruptTime = interruptTime;
}

// Verificar si el botón fue presionado
bool Encoder::isButtonPressed() {
    bool wasPressed = buttonPressed;
    buttonPressed = false;  // Restablecer después de leer
    return wasPressed;
}

// Obtener la posición actual del encoder
int Encoder::getPosition() {
    if (position > encoderMaxPosition) {
        setPosition(encoderMaxPosition);
    } else if (position < encoderMinPosition) {
        setPosition(encoderMinPosition);
    }
    return position;
}

// Establecer la posición del encoder
void Encoder::setPosition(int pos) {
    position = pos;
}

// Establecer la posición máxima del encoder
void Encoder::setMaxPosition(int maxPos) {
    encoderMaxPosition = maxPos;
    if (position > encoderMaxPosition) setPosition(encoderMaxPosition);
}

// Establecer la posición mínima del encoder
void Encoder::setMinPosition(int minPos) {
    encoderMinPosition = minPos;
    if (position < encoderMinPosition) setPosition(encoderMinPosition);
}

// Verificar si el encoder se movió
bool Encoder::moved(){
    static int last_position = 0;
    if (last_position != position) {
        last_position = position;
        return true;
    }
    return false;
}

// Función de actualización (actualmente no hace nada)
void Encoder::update() {
    // Nada que hacer aquí
}

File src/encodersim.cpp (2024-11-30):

#include "encodersim.h"

SimulatedEncoder::SimulatedEncoder()
    : position(0), buttonPressed(false), encoderMaxPosition(10), encoderMinPosition(1) { }

// Inicializa el encoder simulado e imprime los comandos disponibles
void SimulatedEncoder::init() {
    Serial.println("SimulatedEncoder inicializado.");
    Serial.println("Comandos:");
    Serial.print("  '"); Serial.print(SIMENCODER_UP); Serial.println("' - Girar hacia arriba (incrementar posición)");
    Serial.print("  '"); Serial.print(SIMENCODER_DOWN); Serial.println("' - Girar hacia abajo (decrementar posición)");
    Serial.print("  '"); Serial.print(SIMENCODER_PRESS); Serial.println("' - Pulsar el botón");
}

// Actualiza el estado del encoder basado en la entrada serial
void SimulatedEncoder::update() {
    static unsigned long last_time = 0;
    // Procesar la entrada serial sin bloquear
    while (Serial.available() > 0) {
        // Antirrebote
        if (millis() - last_time < SIMENCODER_DEBOUNCE) {
            // Ignorar la entrada actual debido al antirrebote
            Serial.read(); // Descartar el carácter actual
            continue; // Continuar con el siguiente carácter
        }

        last_time = millis(); // Actualizar el tiempo de la última entrada
        char cmd = Serial.read();
        switch (cmd) {
            case SIMENCODER_UP:
                position++;
                if (position > encoderMaxPosition) {
                    position = encoderMaxPosition;
                }
                break;
            case SIMENCODER_DOWN:
                position--;
                if (position < encoderMinPosition) {
                    position = encoderMinPosition;
                }
                break;
            case SIMENCODER_PRESS:
                buttonPressed = true;
                break;
            default:
                // Ignorar otros caracteres
                break;
        }
    }
}

// Verifica si el botón fue presionado
bool SimulatedEncoder::isButtonPressed() {
    bool wasPressed = buttonPressed;
    buttonPressed = false;  // Reiniciar después de leer
    return wasPressed;
}

// Obtiene la posición actual del encoder
int SimulatedEncoder::getPosition() {
    // Asegurarse de que la posición esté dentro de los límites
    if (position > encoderMaxPosition) {
        position = encoderMaxPosition;
    } else if (position < encoderMinPosition) {
        position = encoderMinPosition;
    }
    return position;
}

// Establece la posición del encoder
void SimulatedEncoder::setPosition(int pos) {
    position = pos;
    // Asegurarse de que la posición esté dentro de los límites
    if (position > encoderMaxPosition) {
        position = encoderMaxPosition;
    } else if (position < encoderMinPosition) {
        position = encoderMinPosition;
    }
}

// Establece la posición máxima del encoder
void SimulatedEncoder::setMaxPosition(int maxPos) {
    encoderMaxPosition = maxPos;
    if (position > encoderMaxPosition) {
        position = encoderMaxPosition;
    }
}

// Establece la posición mínima del encoder
void SimulatedEncoder::setMinPosition(int minPos) {
    encoderMinPosition = minPos;
    if (position < encoderMinPosition) {
        position = encoderMinPosition;
    }
}

// Verifica si la posición del encoder ha cambiado
bool SimulatedEncoder::moved(){
    static int last_position = 0;
    if (last_position != position) {
        last_position = position;
        return true;
    }
    return false;
}

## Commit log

2024-11-27 encoder y lcd simulado
2024-11-27 encoder simulado ajustado y menu de mediciones
2024-11-30 pwm working
2024-11-30 adjustments on encoder usage
2024-11-30 kicad project
    [BOM_Semirario1.xlsx, Modulo IO Seminario.kicad_pcb, Modulo IO Seminario.kicad_sch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]
